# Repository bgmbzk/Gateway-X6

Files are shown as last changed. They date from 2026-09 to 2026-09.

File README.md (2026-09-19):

# Gateway-X6 — 6 Katmanlı STM32 Yüksek Hızlı Donanım Tasarımı

Gateway-X6; STM32 mikrokontrolcü mimarisi, harici SDRAM arayüzü ve endüstriyel haberleşme hatlarını bir araya getiren, sinyal bütünlüğü (Signal Integrity) ve güç dağıtımı (Power Distribution) önceliklendirilerek tasarlanmış 6 katmanlı (6-layer) bir PCB projesidir.

---

## 📸 Proje Görselleri

### 1. 3D Kart Görünümü
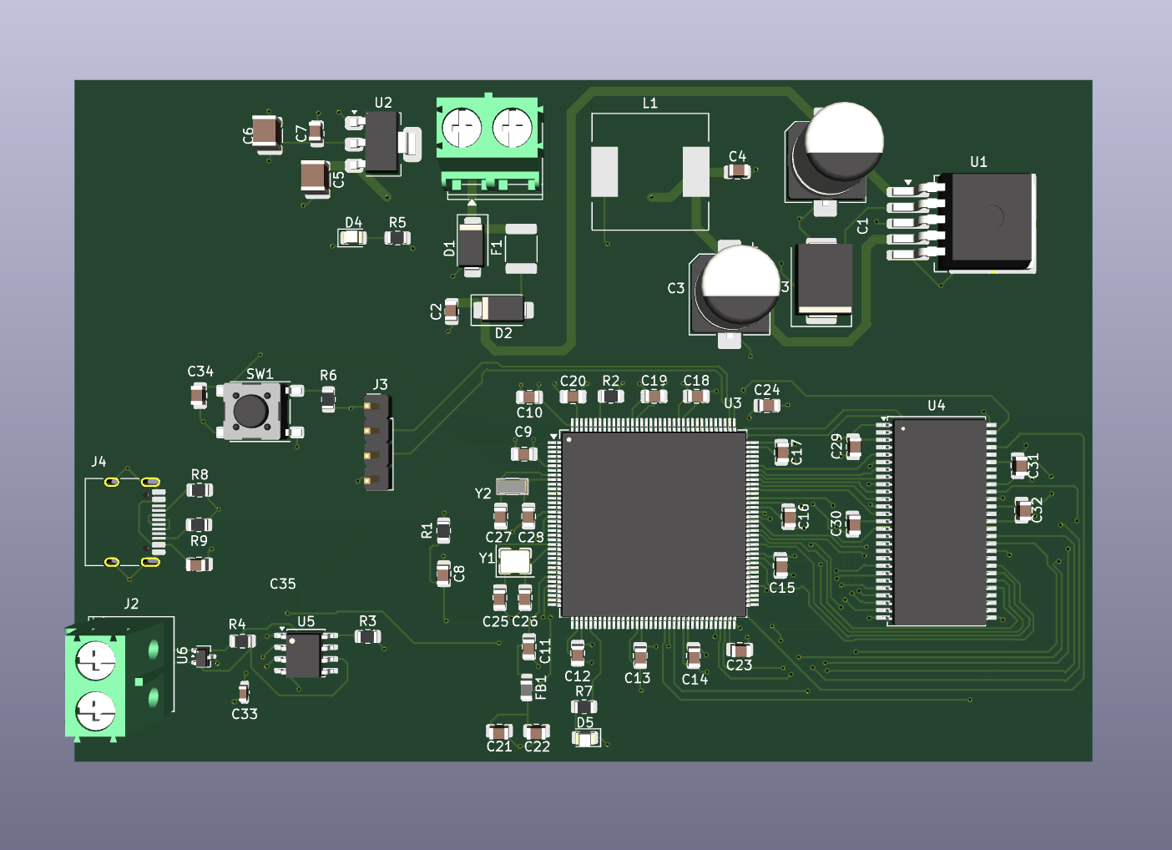
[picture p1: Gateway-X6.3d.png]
3D Görünüm


### 2. PCB Katman Çizimi ve Yönlendirme
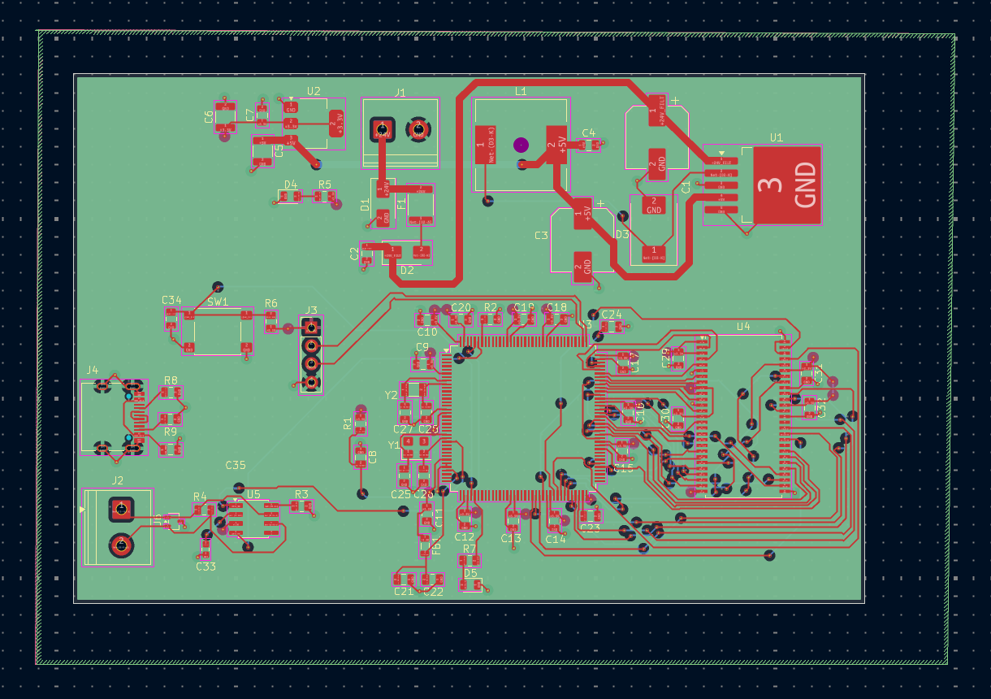
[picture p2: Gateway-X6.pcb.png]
PCB Çizimi


### 3. Şematik Tasarım
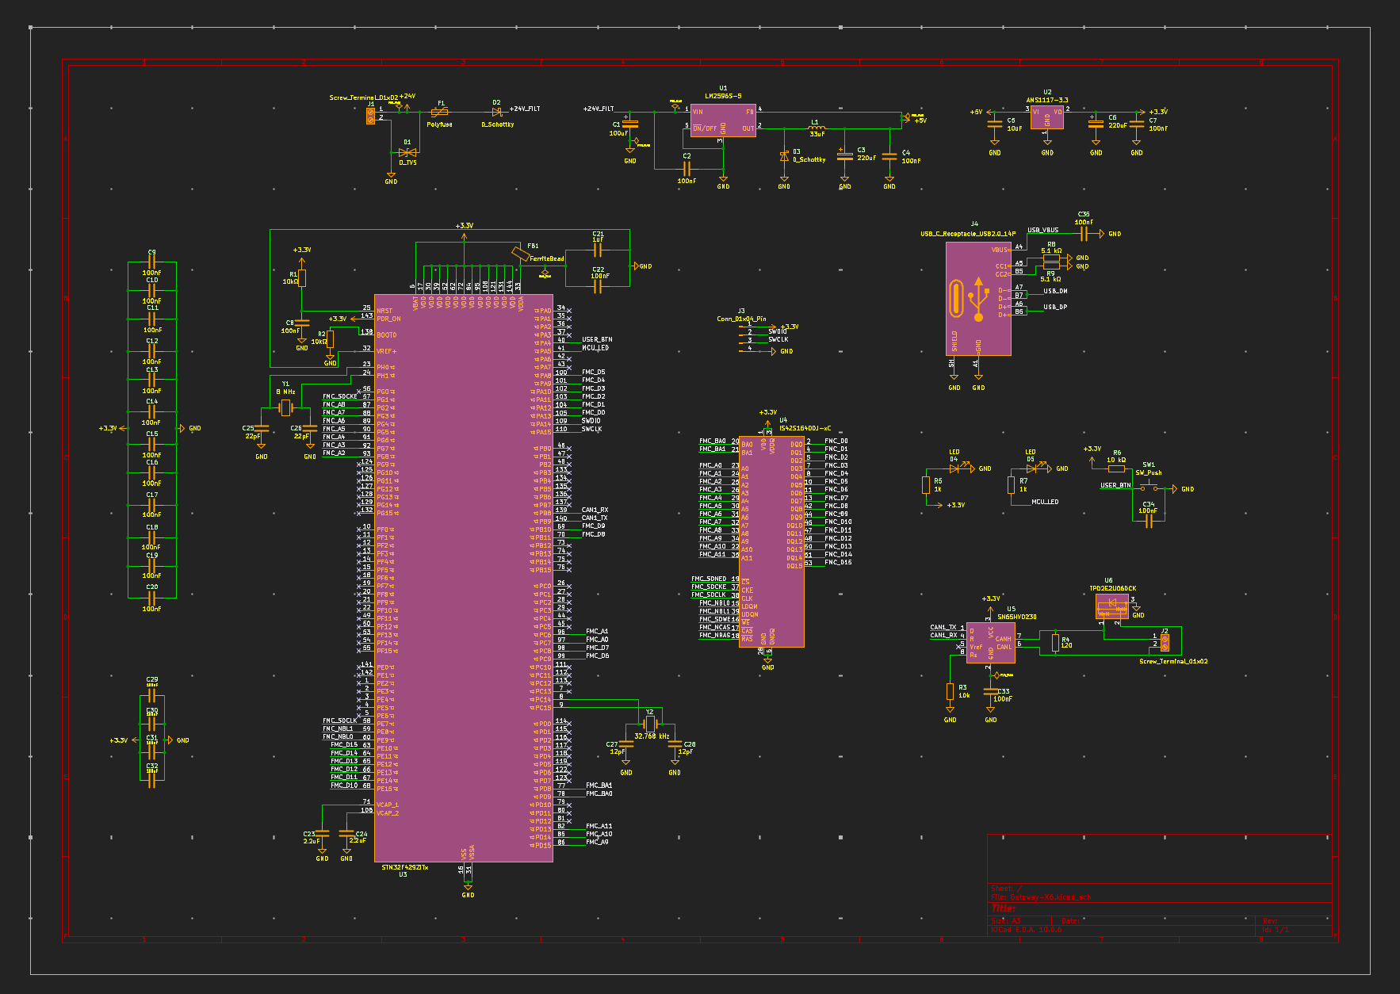
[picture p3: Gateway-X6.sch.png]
Şematik Tasarım


---

## Proje Motivasyonu ve Öğrenim Hedefleri

Bu proje; hem profesyonel donanım tasarımı standartlarını pratiğe dökmek hem de karmaşık mimarilerle çalışırken karşılaşılan zorlukları bizzat tecrübe etmek amacıyla geliştirilmiştir:

- **STM32 Tasarım Standartları:** STM32 mikrokontrolcü ekosisteminin yüksek hızlı çevre birimleri, kristal osilatör hatları ve decoupling (dekaplaj) kondansatör yerleşim standartlarını derinlemesine uygulamak.
- **6 Katmanlı Yığın Yapısı (Stackup):** 2 veya 4 katmanlı yapıların ötesine geçerek, gürültü bağışıklığı ve kesintisiz referans düzlemleri (GND/PWR plane) sunan 6 katmanlı mimariyi deneyimlemek.
- **Sinyal ve Adres Hatlarında Karmaşıklık Yönetimi:** STM32 ile SDRAM arasındaki FMC (Flexible Memory Controller) arayüzünde yer alan onlarca yüksek hızlı veri, adres ve kontrol hattını (FMC_SDCKE, FMC_SDCLK vb.) çakışmasız, izole ve doğru pin eşlemeleriyle yönlendirmek; bu süreçteki etiketleme (net management) ve adresleme karmaşıklıklarını büyük bir sabır ve hassasiyetle çözmek.

---

## Katman Mimarisi (6-Layer Stackup)

Kartın sinyal bütünlüğünü korumak ve EMC/EMI performansını artırmak için aşağıdaki katman dizilimi uygulanmıştır:

1. **Top Layer (`F.Cu`):** Yüksek Hızlı Sinyaller ve Komponent Yerleşimi
2. **GND Plane (`GND`):** Üst Katman İçin Kesintisiz Toprak Referans Düzlemi
3. **Inner Signal (`SIG1`):** İç Sinyal Yönlendirme Katmanı
4. **GND2 Plane (`GND2`):** Güç Katmanı İçin İkincil Toprak Düzlemi
5. **Power Plane (`PWR`):** $+3.3\text{V}$ Besleme Düzlemi
6. **Bottom Layer (`B.Cu`):** Alt Sinyaller ve Kalın Güç Yolları ($+24\text{V}$, $+5\text{V}$)

---

## Güç Mimarisi ve Yönlendirme

- **$+24\text{V}$ Filtreli Endüstriyel Giriş:** Giriş gürültülerini bastıran filtreleme yapısı ve $1.0\text{ mm}$ kalınlığında yüksek akım hatları.
- **Kademeli Regülasyon:** $+24\text{V} \rightarrow +5\text{V}$ ve $+5\text{V} \rightarrow +3.3\text{V}$ ana hatlar üzerinden kararlı voltaj dağıtımı.
- **Hassas Sinyal İzolasyonu:** Hızlı saat hatları (FMC_SDCLK) ve kontrol hatları, hata ayıklama (SWCLK) ve güç hatlarından izole edilerek cross-talk (çapraz gürültü) engellenmiştir.

---

## Proje Dizin Yapısı

```text
Gateway-X6/
├── Hardware/               # KiCad şematik ve PCB çizim dosyaları (.kicad_sch, .kicad_pcb)
├── Production/             # Üretime hazır Gerber ve Drill ZIP dosyaları
├── Docs/                   # Şematik PDF çıktıları ve teknik dokümanlar
├── Images/                 # Proje görselleri (Gateway-X6.3d.png, Gateway-X6.pcb.png, Gateway-X6.kch.png)
├── .gitignore
└── README.md

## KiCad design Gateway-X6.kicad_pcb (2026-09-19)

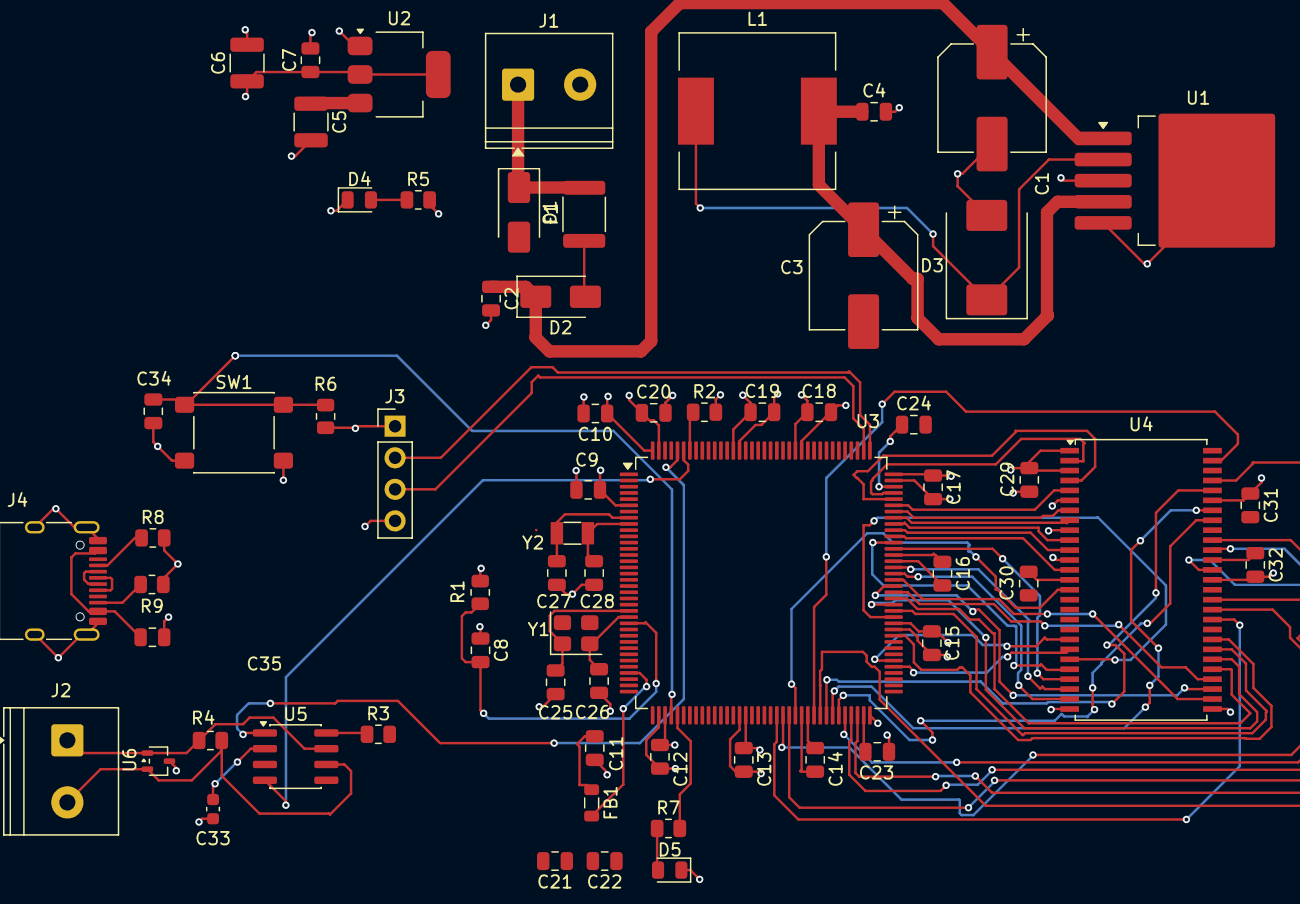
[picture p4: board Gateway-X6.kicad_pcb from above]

Board: 6 copper layers, 65 parts (0 on the bottom side), 67 nets.

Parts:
C1: 100uF; CP_Elec_8x10.5
C2, C4, C7, C8, C9, C10, C11, C12, C13, C14, C15, C16, C17, C18, C19, C20, C22, C29, C30, C31, C32, C34, C35: 100nF; C_0805_2012Metric
C3: 220uF; CP_Elec_8x10.5
C5: 10uF; C_1210_3225Metric
C6: 220uF; C_1210_3225Metric
C21: 1uF; C_0805_2012Metric
C23, C24: 2.2uF; C_0805_2012Metric
C25, C26: 22pF; C_0805_2012Metric
C27, C28: 12pF; C_0805_2012Metric
C33: 100nF; C_0603_1608Metric
D1: D_TVS; D_SMA
D2: D_Schottky; D_SMA
D3: D_Schottky; D_SMC
D4, D5: LED; LED_0805_2012Metric
F1: Polyfuse; Fuse_1812_4532Metric
FB1: FerriteBead; L_0805_2012Metric
J1, J2: Screw_Terminal_01x02; TerminalBlock_Phoenix_PT-1,5-2-5.0-H_1x02_P5.00mm_Horizontal
J3: Conn_01x04_Pin; PinHeader_1x04_P2.54mm_Vertical
J4: USB_C_Receptacle_USB2.0_14P; USB_C_Receptacle_HRO_TYPE-C-31-M-12
L1: 33uF; L_12x12mm_H8mm
R1, R2: 10kΩ; R_0805_2012Metric
R3: 10k; R_0805_2012Metric
R4: 120; R_0805_2012Metric
R5, R7: 1k; R_0805_2012Metric
R6: 10 kΩ; R_0805_2012Metric
R8, R9: 5.1 kΩ; R_0805_2012Metric
SW1: SW_Push; SW_SPST_PTS645Sx43SMTR92
U1: LM2596S-5; TO-263-5_TabPin3
U2: AMS1117-3.3; SOT-223-3_TabPin2
U3: STM32F429ZITx; LQFP-144_20x20mm_P0.5mm
U4: IS42S16400J-xC; TSOP-II-54_22.2x10.16mm_P0.8mm
U5: SN65HVD230; SOIC-8_3.9x4.9mm_P1.27mm
U6: TPD2E2U06DCK; SOT-323_SC-70
Y1: 8 MHz; Crystal_SMD_3225-4Pin_3.2x2.5mm
Y2: 32.768 kHz; Crystal_SMD_3215-2Pin_3.2x1.5mm

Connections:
+3.3V: C6.1, C7.1, C9.1, C10.1, C11.1, C12.1, C13.1, C14.1, C15.1, C16.1, C17.1, C18.1, C19.1, C20.1, C29.1, C30.1, C31.1, C32.1, FB1.1, J3.1, R1.1, R5.2, R6.1, U2.2 (VO), U3.6 (VBAT), U3.17 (VDD), U3.30 (VDD), U3.39 (VDD), U3.52 (VDD), U3.62 (VDD), U3.72 (VDD), U3.84 (VDD), U3.95 (VDD), U3.108 (VDD), U3.121 (VDD), U3.131 (VDD), U3.143 (PDR_ON), U3.144 (VDD), U4.1 (VDD), U4.3 (VDDQ), U4.9 (VDDQ), U4.14 (VDD), U4.27 (VDD), U4.43 (VDDQ), U4.49 (VDDQ), U5.3 (VCC)
+5V: C3.1, C4.1, C5.1, L1.2, U1.4 (FB), U2.3 (VI)
+24V: D1.1 (A1), F1.2, J1.1
/+24V_FILT: C1.1, C2.1, D2.1 (K), U1.1 (VIN)
/CAN1_RX: U3.139 (PB8), U5.4 (R)
/CAN1_TX: U3.140 (PB9), U5.1 (D)
/FMC_A0: U3.97 (PC7), U4.23 (A0)
/FMC_A1: U3.96 (PC6), U4.24 (A1)
/FMC_A2: U3.93 (PG8), U4.25 (A2)
/FMC_A3: U3.92 (PG7), U4.26 (A3)
/FMC_A4: U3.91 (PG6), U4.29 (A4)
/FMC_A5: U3.90 (PG5), U4.30 (A5)
/FMC_A6: U3.89 (PG4), U4.31 (A6)
/FMC_A7: U3.88 (PG3), U4.32 (A7)
/FMC_A8: U3.87 (PG2), U4.33 (A8)
/FMC_A9: U3.86 (PD15), U4.34 (A9)
/FMC_A10: U3.85 (PD14), U4.22 (A10)
/FMC_A11: U3.82 (PD13), U4.35 (A11)
/FMC_BA0: U3.78 (PD9), U4.20 (BA0)
/FMC_BA1: U3.77 (PD8), U4.21 (BA1)
/FMC_D0: U3.105 (PA13), U4.2 (DQ0)
/FMC_D1: U3.104 (PA12), U4.4 (DQ1)
/FMC_D2: U3.103 (PA11), U4.5 (DQ2)
/FMC_D3: U3.102 (PA10), U4.7 (DQ3)
/FMC_D4: U3.101 (PA9), U4.8 (DQ4)
/FMC_D5: U3.100 (PA8), U4.10 (DQ5)
/FMC_D6: U3.99 (PC9), U4.11 (DQ6)
/FMC_D7: U3.98 (PC8), U4.13 (DQ7)
/FMC_D8: U3.70 (PB11), U4.42 (DQ8)
/FMC_D9: U3.69 (PB10), U4.44 (DQ9)
/FMC_D10: U3.68 (PE15), U4.45 (DQ10)
/FMC_D11: U3.67 (PE14), U4.47 (DQ11)
/FMC_D12: U3.66 (PE13), U4.48 (DQ12)
/FMC_D13: U3.65 (PE12), U4.50 (DQ13)
/FMC_D14: U3.64 (PE11), U4.51 (DQ14)
/FMC_D15: U3.63 (PE10), U4.53 (DQ15)
/FMC_NBL0: U3.60 (PE9), U4.15 (LDQM)
/FMC_NBL1: U3.59 (PE8), U4.39 (UDQM)
/FMC_SDCKE: U3.57 (PG1), U4.37 (CKE)
/FMC_SDCLK: U3.58 (PE7), U4.38 (CLK)
/MCU_LED: R7.2, U3.41 (PA5)
/SWCLK: J3.3, U3.110 (PA15)
/SWDIO: J3.2, U3.109 (PA14)
/USB_DM: J4.A7 (D-), J4.B7 (D-)
/USB_DP: J4.A6 (D+), J4.B6 (D+)
/USB_VBUS: C35.1, J4.A4 (VBUS), J4.A9 (VBUS), J4.B4 (VBUS), J4.B9 (VBUS)
/USER_BTN: C34.1, R6.2, SW1.1, U3.40 (PA4)
GND: C1.2, C2.2, C3.2, C4.2, C5.2, C6.2, C7.2, C8.1, C9.2, C10.2, C11.2, C12.2, C13.2, C14.2, C15.2, C16.2, C17.2, C18.2, C19.2, C20.2, C21.1, C22.1, C23.2, C24.2, C25.2, C26.2, C27.2, C28.2, C29.2, C30.2, C31.2, C32.2, C33.2, C34.2, C35.2, D1.2 (A2), D3.2 (A), D4.1 (K), D5.1 (K), J1.2, J3.4, J4.A1 (GND), J4.A12 (GND), J4.B1 (GND), J4.B12 (GND), J4.SH (SHIELD), R2.2, R3.2, R8.2, R9.2, SW1.2, U1.3 (GND), U1.5 (~ON/OFF), U2.1 (GND), U3.16 (VSS), U3.31 (VSSA), U3.32 (VREF+), U3.38 (VSS), U3.51 (VSS), U3.61 (VSS), U3.83 (VSS), U3.94 (VSS), U3.107 (VSS), U3.120 (VSS), U3.130 (VSS), U4.6 (GNDQ), U4.12 (GNDQ), U4.28 (GND), U4.41 (GND), U4.46 (GNDQ), U4.52 (GNDQ), U4.54 (GND), U6.3
unnamed: D2.2 (A), F1.1
unnamed: D3.1 (K), L1.1, U1.2 (OUT)
unnamed: D4.2 (A), R5.1
unnamed: D5.2 (A), R7.1
unnamed: J2.1, R4.1, U5.7 (CANH), U6.1
unnamed: J2.2, R4.2, U5.6 (CANL), U6.2
unnamed: J4.A5 (CC1), R8.1
unnamed: J4.B5 (CC2), R9.1
unnamed: R2.1, U3.138 (BOOT0)
unnamed: C8.2, R1.2, U3.25 (NRST)
unnamed: C27.1, U3.8 (PC14), Y2.1
unnamed: C28.1, U3.9 (PC15), Y2.2
unnamed: C25.1, U3.23 (PH0), Y1.1
unnamed: C26.1, U3.24 (PH1), Y1.2
unnamed: C23.1, U3.71 (VCAP_1)
unnamed: C24.1, U3.106 (VCAP_2)
unnamed: C21.2, C22.2, FB1.2, U3.33 (VDDA)
unnamed: C33.1, U5.2 (GND)
unnamed: R3.1, U5.8 (Rs)
